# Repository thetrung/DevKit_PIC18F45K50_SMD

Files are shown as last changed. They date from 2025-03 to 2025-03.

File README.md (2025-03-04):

DevKit PIC18F45K50-SMD / Mini-USB
===================================
Basic USB Type-B DevKit I made to learn about **PIC18F45K50** microcontroller.

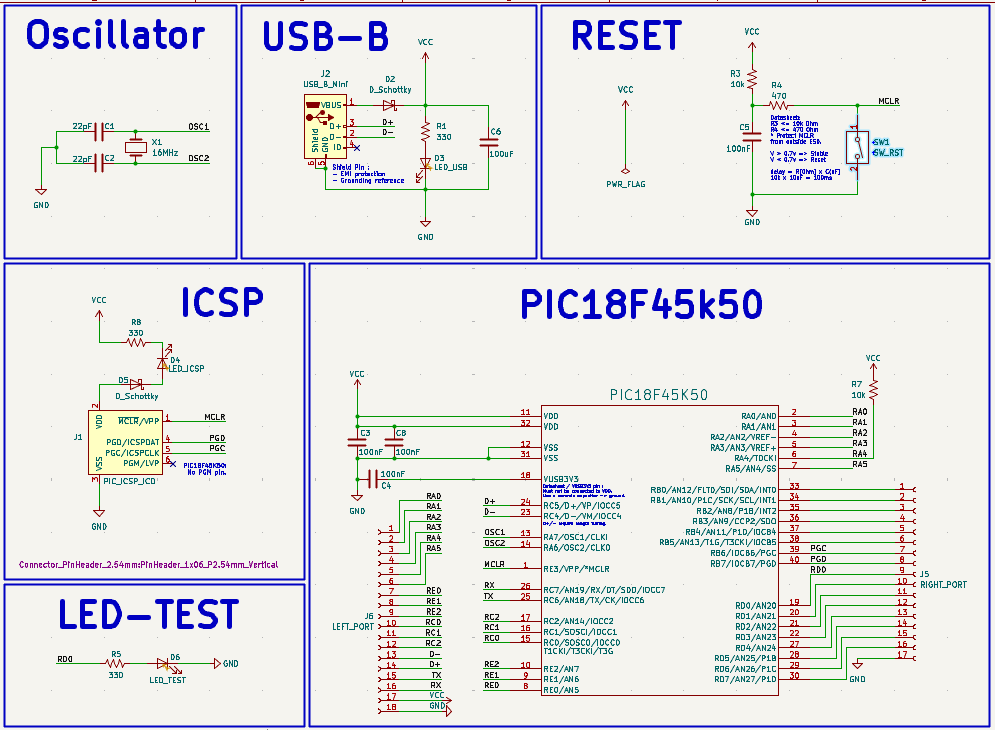
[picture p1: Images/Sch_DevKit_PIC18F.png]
overview


- **PIC18F45K50-I/MV** will be used specifically as UQFN-40(5x5) instead DIP-40 package in previous THT version.

I actually tried to put all SMD components on front side only. Used Mini-USB instead of USB-B in previous THT version. So this isn't optimized by any mean, just simply a practice to experience what SMD PCB Design look like & what challenge compare to THT ? Although initial goal was same size to a DIP-40. But Port hints are so valuable to remove.

### 1. Basic functionality :
- USB-powered 5V supply.
- USB-HID controllable with PIC18F45k50 with D+/D- pins.
- Reset Button -> Trigger MLCR-pin pull-down -> GND.
- Programming/Debugging with PICKIT-3 via ICSP pins.
- 5 pluggable PORTS : RA, RB, RC, RD, RE.
- LED at RD0 for Blink Test.

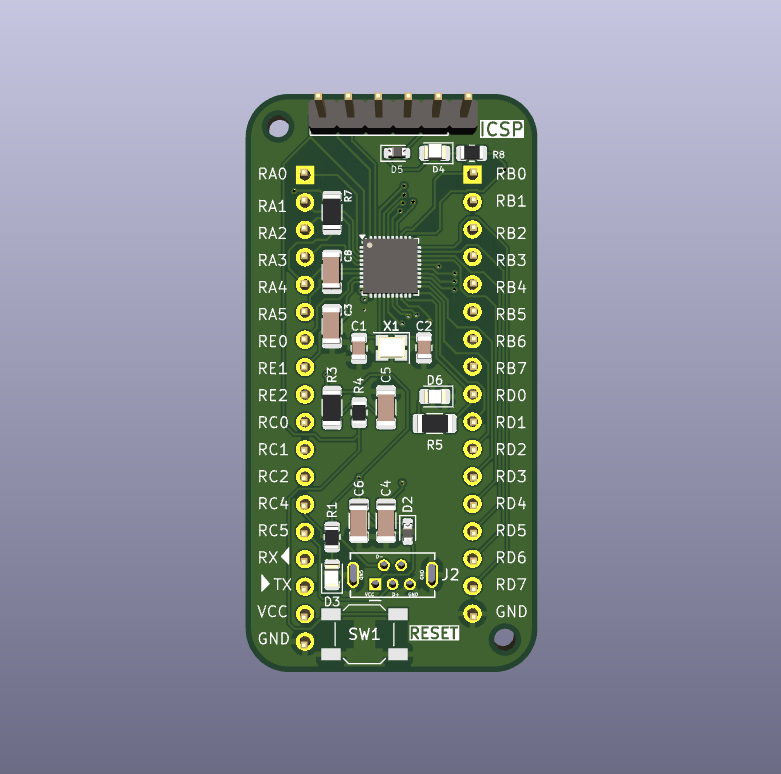
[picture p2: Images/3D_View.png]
3d_parts

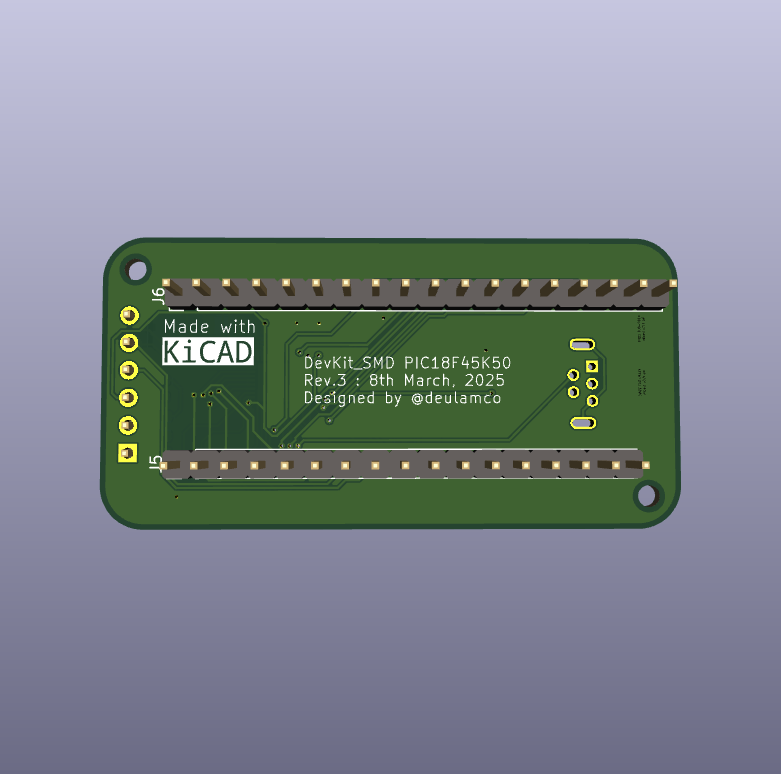
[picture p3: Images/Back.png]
back


### 2. TODO / Future extensions :
- Add Array : 
    - 4x4 12mm-Buttons pad.
    - 4x4 LEDs grid.
    - 16 Relays
      
- Add Gyro sensor.
- Add distance sensor.
- Add HLK-PM01 Module & Relay.
- Add built-in UART w/ CH340 !?
- Add LCD2004 support, with/without I2C module.
- Add WIFI/LoRA/Bluetooth by ESP32 support (?).

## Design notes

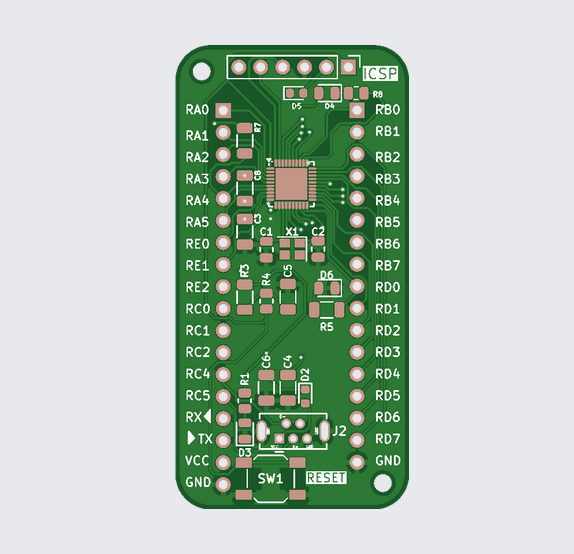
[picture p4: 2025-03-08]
Images/TOP_Placement.png

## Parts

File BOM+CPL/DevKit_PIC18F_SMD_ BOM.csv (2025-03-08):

Comment | Designator | Footprint | LCSC Part Number
22pF | C2,C1 | C_0805_2012Metric | C1804
100nF | C3,C5,C4,C8 | C_1206_3216Metric | C24497
100uF | C6 | C_1206_3216Metric | C15008
D_Schottky | D2,D5 | D_0603_1608Metric | C3758192
LED_TEST | D3,D4,D6 | LED_0805_2012Metric | C2297
PIC18F45K50-I/MV | PIC18F45K50 | QFN-40-1EP_5x5mm_P0.4mm_EP3.6x3.6mm | C638925
10k | R3,R7 | R_1206_3216Metric | C17902
470Ohm | R8,R4,R5,R1 | R_0805_2012Metric | C17710
16MHz | X1 | Crystal_SMD_2520-4Pin_2.5x2.0mm | C13738
SW_RST | SW1 | SW_SPST_SKQG_WithStem | C318884

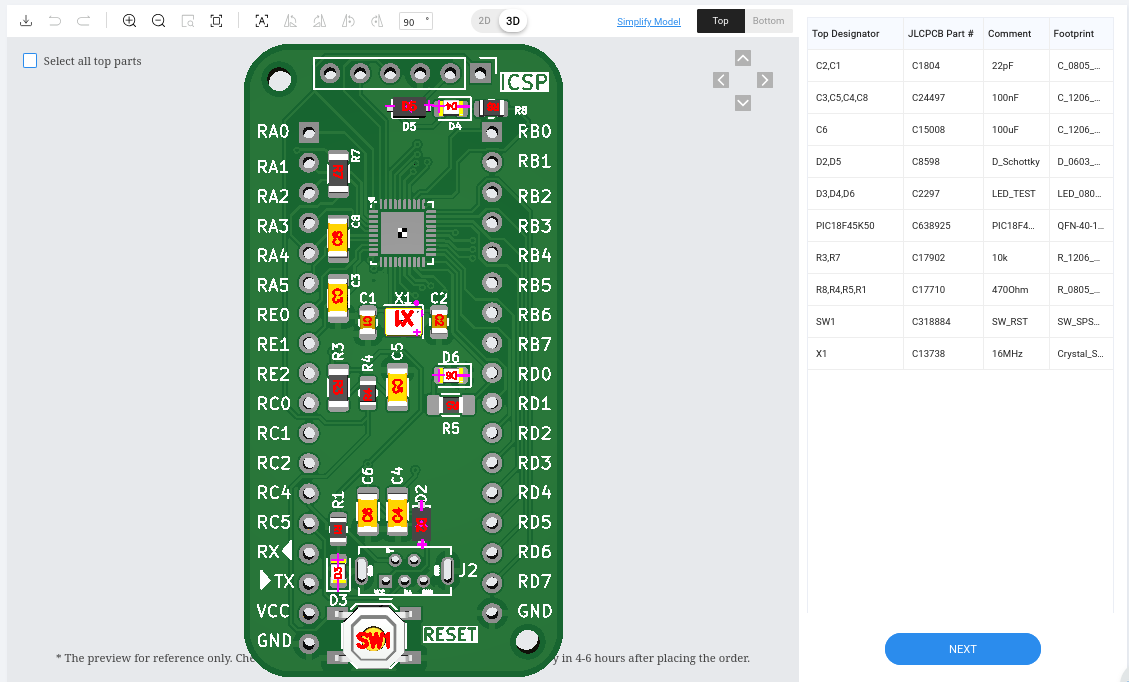
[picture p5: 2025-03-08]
Images/TOP_Parts.png

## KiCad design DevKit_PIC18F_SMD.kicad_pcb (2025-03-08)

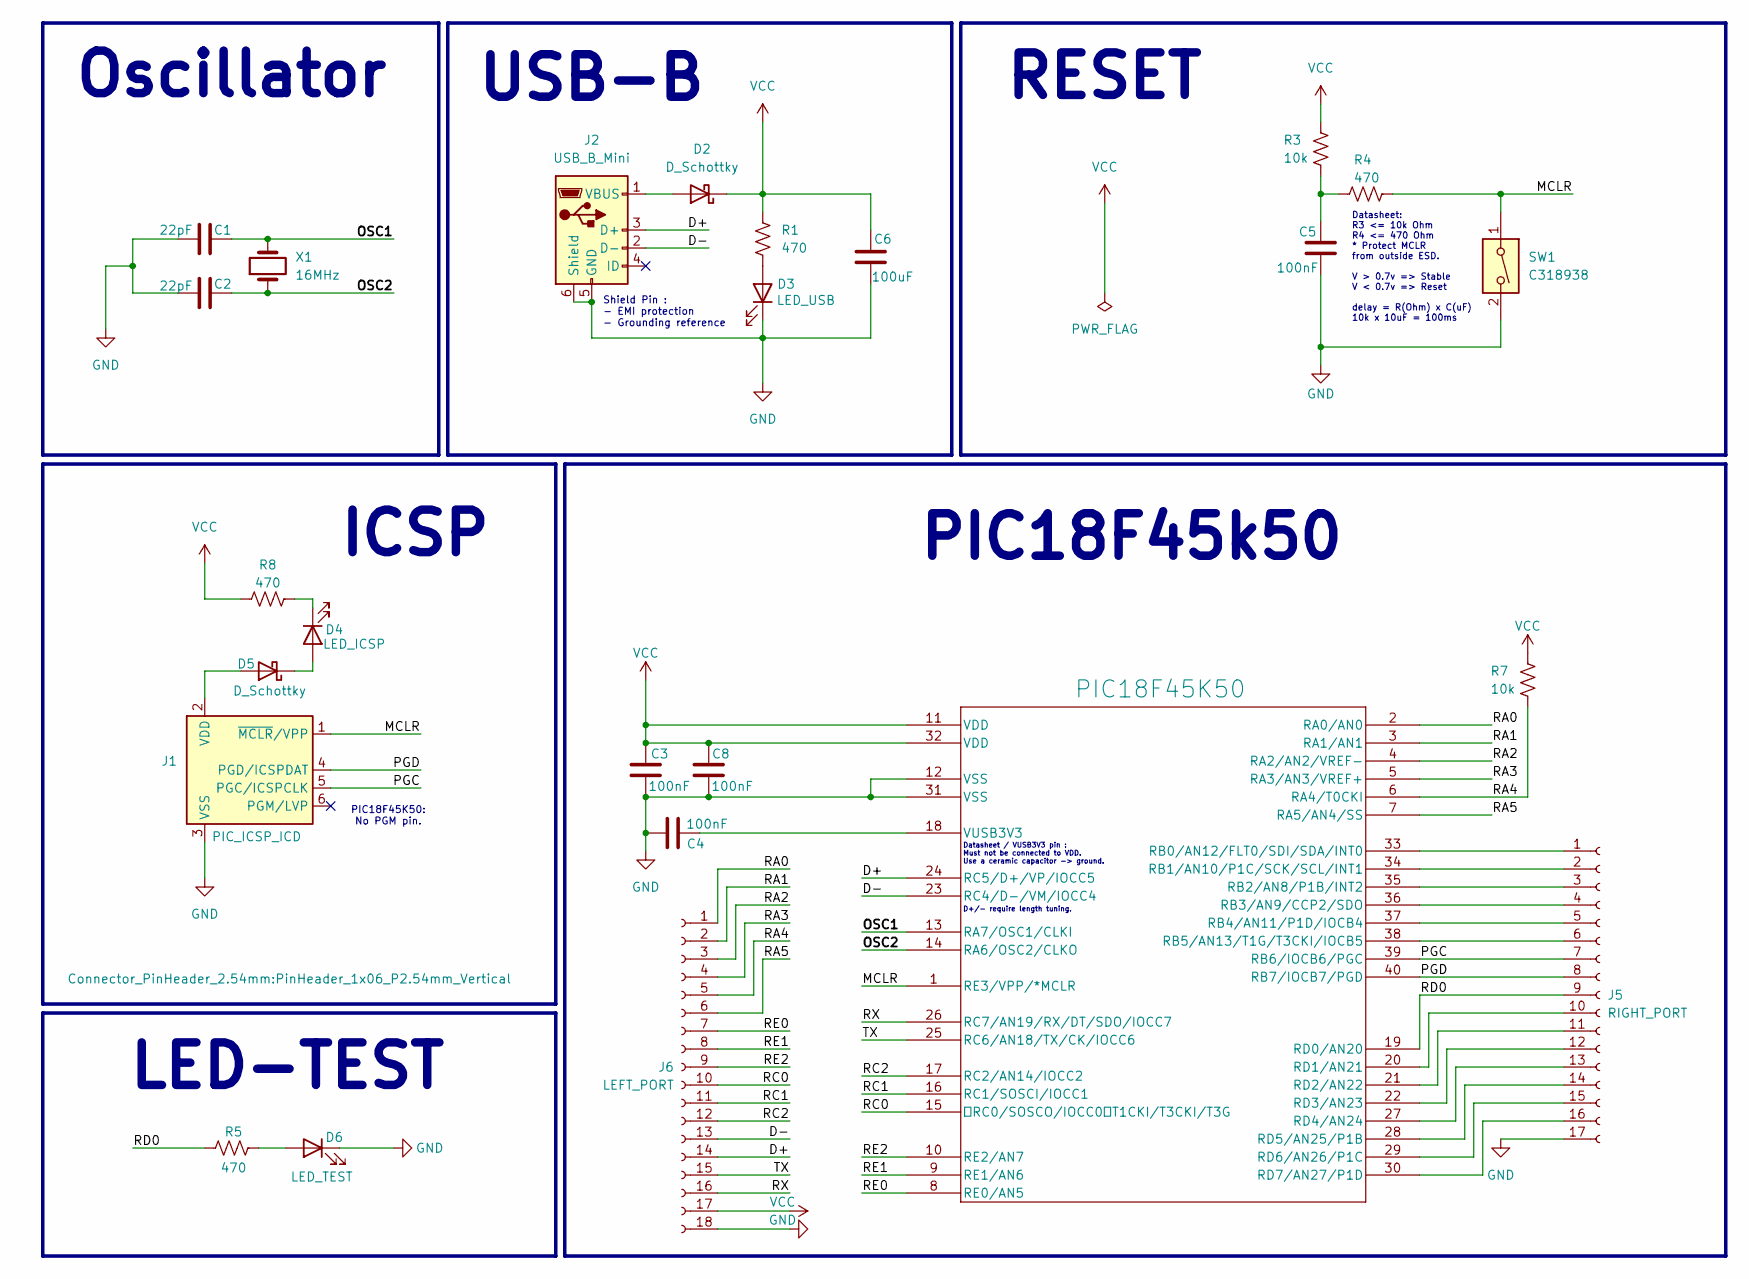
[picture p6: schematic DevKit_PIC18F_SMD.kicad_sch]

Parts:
C1, C2: 22pF; C_0805_2012Metric
C3, C4, C5, C8: 100nF; C_1206_3216Metric
C6: 100uF; C_1206_3216Metric
D2, D5: D_Schottky; D_0603_1608Metric
D3: LED_USB; LED_0805_2012Metric
D4: LED_ICSP; LED_0805_2012Metric
D6: LED_TEST; LED_0805_2012Metric
J1: PIC_ICSP_ICD; PinHeader_1x06_P2.54mm_Vertical
J2: USB_B_Mini; USB_Mini-B_Tensility_54-00023_Vertical
J5: RIGHT_PORT; PinHeader_1x17_P2.54mm_Vertical
J6: LEFT_PORT; PinHeader_1x18_P2.54mm_Vertical
PIC18F45K50: PIC18F45K50-I/MV; QFN-40-1EP_5x5mm_P0.4mm_EP3.6x3.6mm
R1, R4, R5, R8: 470; R_0805_2012Metric
R3, R7: 10k; R_1206_3216Metric
SW1: C318938; SW_SPST_SKQG_WithStem
X1: 16MHz; Crystal_SMD_2520-4Pin_2.5x2.0mm

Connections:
/D+: J2.3 (D+), J6.14, PIC18F45K50.24 (RC5/D+/VP/IOCC5)
/D-: J2.2 (D-), J6.13, PIC18F45K50.23 (RC4/D-/VM/IOCC4)
/MCLR: J1.1 (~MCLR/VPP), PIC18F45K50.1 (RE3/VPP/*MCLR), R4.1, SW1.1
/OSC1: C1.1, PIC18F45K50.13 (RA7/OSC1/CLKI), X1.2
/OSC2: C2.1, PIC18F45K50.14 (RA6/OSC2/CLKO), X1.1
/PGC: J1.5 (PGC/ICSPCLK), J5.7, PIC18F45K50.39 (RB6/IOCB6/PGC)
/PGD: J1.4 (PGD/ICSPDAT), J5.8, PIC18F45K50.40 (RB7/IOCB7/PGD)
/RA0: J6.1, PIC18F45K50.2 (RA0/AN0)
/RA1: J6.2, PIC18F45K50.3 (RA1/AN1)
/RA2: J6.3, PIC18F45K50.4 (RA2/AN2/VREF-)
/RA3: J6.4, PIC18F45K50.5 (RA3/AN3/VREF+)
/RA4: J6.5, PIC18F45K50.6 (RA4/T0CKI), R7.2
/RA5: J6.6, PIC18F45K50.7 (RA5/AN4/SS)
/RC0: J6.10, PIC18F45K50.15 (RC0/SOSCO/IOCC0 T1CKI/T3CKI/T3G)
/RC1: J6.11, PIC18F45K50.16 (RC1/SOSCI/IOCC1)
/RC2: J6.12, PIC18F45K50.17 (RC2/AN14/IOCC2)
/RD0: J5.9, PIC18F45K50.19 (RD0/AN20), R5.1
/RE0: J6.7, PIC18F45K50.8 (RE0/AN5)
/RE1: J6.8, PIC18F45K50.9 (RE1/AN6)
/RE2: J6.9, PIC18F45K50.10 (RE2/AN7)
/RX: J6.16, PIC18F45K50.26 (RC7/AN19/RX/DT/SDO/IOCC7)
/TX: J6.15, PIC18F45K50.25 (RC6/AN18/TX/CK/IOCC6)
GND: C1.2, C2.2, C3.2, C4.1, C5.1, C6.1, C8.2, D3.1 (K), D6.1 (K), J1.3 (VSS), J2.5 (GND), J2.6 (Shield), J5.17, J6.18, PIC18F45K50.12 (VSS), PIC18F45K50.31 (VSS), SW1.2
unnamed: C5.2, R3.2, R4.2
unnamed: D2.2 (A), J2.1 (VBUS)
unnamed: D3.2 (A), R1.2
unnamed: D4.2 (A), D5.1 (K)
unnamed: D4.1 (K), R8.2
unnamed: D5.2 (A), J1.2 (VDD)
unnamed: D6.2 (A), R5.2
unnamed: J5.1, PIC18F45K50.33 (RB0/AN12/FLT0/SDI/SDA/INT0)
unnamed: J5.2, PIC18F45K50.34 (RB1/AN10/P1C/SCK/SCL/INT1)
unnamed: J5.3, PIC18F45K50.35 (RB2/AN8/P1B/INT2)
unnamed: J5.4, PIC18F45K50.36 (RB3/AN9/CCP2/SDO)
unnamed: J5.5, PIC18F45K50.37 (RB4/AN11/P1D/IOCB4)
unnamed: J5.6, PIC18F45K50.38 (RB5/AN13/T1G/T3CKI/IOCB5)
unnamed: J5.10, PIC18F45K50.20 (RD1/AN21)
unnamed: J5.11, PIC18F45K50.21 (RD2/AN22)
unnamed: J5.12, PIC18F45K50.22 (RD3/AN23)
unnamed: J5.13, PIC18F45K50.27 (RD4/AN24)
unnamed: J5.14, PIC18F45K50.28 (RD5/AN25/P1B)
unnamed: J5.15, PIC18F45K50.29 (RD6/AN26/P1C)
unnamed: J5.16, PIC18F45K50.30 (RD7/AN27/P1D)
unnamed: C4.2, PIC18F45K50.18 (VUSB3V3)
VCC: C3.1, C6.2, C8.1, D2.1 (K), J6.17, PIC18F45K50.11 (VDD), PIC18F45K50.32 (VDD), R1.1, R3.1, R7.1, R8.1

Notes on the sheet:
RESET
USB-B
D+/- require length tuning.
ICSP
Shield Pin : - EMI protection - Grounding reference
Datasheet / VUSB3V3 pin : Must not be connected to VDD. Use a ceramic capacitor -> ground.
LED-TEST
Datasheet: R3 <= 10k Ohm R4 <= 470 Ohm * Protect MCLR from outside ESD. V > 0.7v => Stable V < 0.7v => Reset delay = R(Ohm) x C(uF) 10k x 10uF = 100ms
Oscillator
PIC18F45K50: No PGM pin.
PIC18F45k50

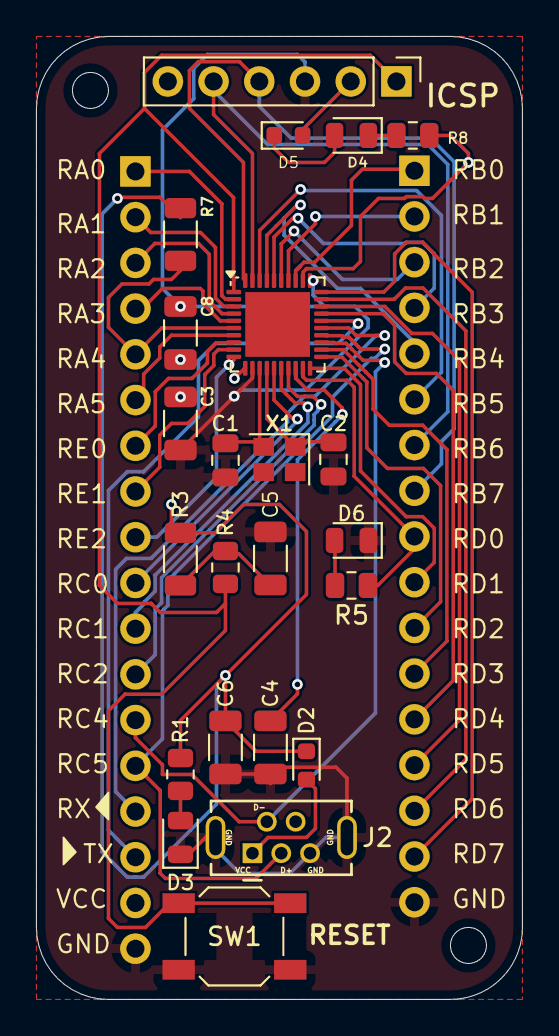
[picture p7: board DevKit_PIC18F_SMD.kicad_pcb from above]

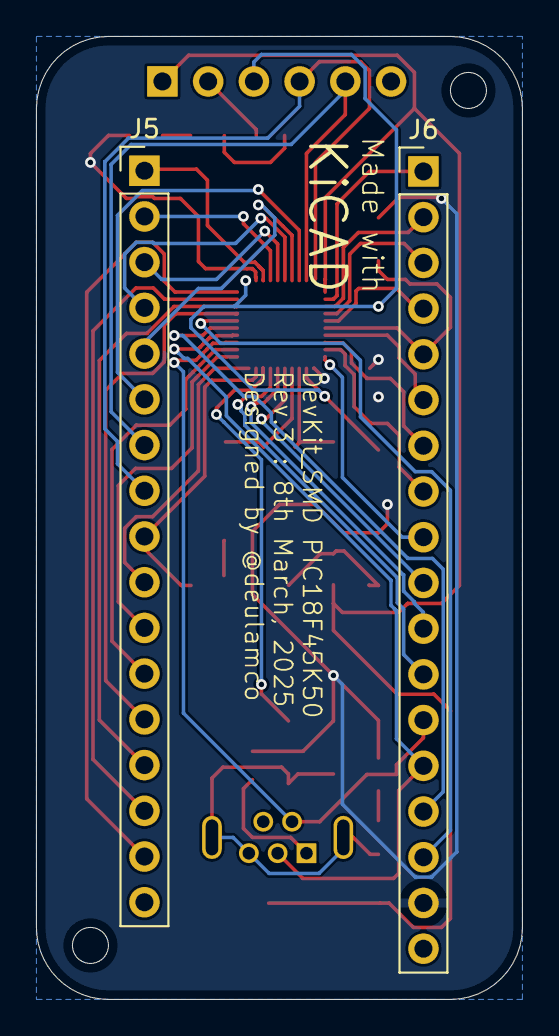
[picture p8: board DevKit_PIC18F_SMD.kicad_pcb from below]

Board: 2 copper layers, 27.0 x 53.5 mm, 25 parts (2 on the bottom side), 45 nets.

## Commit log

2025-03-04 made SMD version of prev DevKit rev.5
    [DevKit_PIC18F_SMD.kicad_pcb, DevKit_PIC18F_SMD.kicad_sch, PDIP40_P_MCH.stl]
2025-03-04 update images & comment.
    [DevKit_PIC18F_SMD.kicad_pcb, DevKit_PIC18F_SMD.kicad_sch]
2025-03-05 Added VCC/GND pins
    [DevKit_PIC18F_SMD.kicad_pcb, DevKit_PIC18F_SMD.kicad_sch]
2025-03-05 Remove PWR flag in Reset part, since we updated wrong pin setup in symbol PIC18F45K50.
    [DevKit_PIC18F_SMD.kicad_pcb, DevKit_PIC18F_SMD.kicad_sch, PDIP40_P_MCH.stl]
2025-03-07 rev.2 : and GND -> Left sockets & move RST_Button to bottom.
    [DevKit_PIC18F_SMD.kicad_pcb, DevKit_PIC18F_SMD.kicad_sch]
2025-03-07 Add mapped BOM+CPL
    [DevKit_PIC18F_SMD_ BOM.csv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]
2025-03-07 Optimize BOM cost to ~0/2pcs but minium 6 in total.
    [DevKit_PIC18F_SMD_ BOM.csv]
2025-03-08 Rev.3 : refine part-selection for JLCPCB fabrication & silkscreen.
    [DevKit_PIC18F_SMD.kicad_pcb, DevKit_PIC18F_SMD.kicad_sch, DevKit_PIC18F_SMD_ BOM.csv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]
2025-03-08 Fix R5 size 1206 -> 0805 & BOM of D5,D2 -> C3758192
    [DevKit_PIC18F_SMD.kicad_pcb, DevKit_PIC18F_SMD.kicad_sch, DevKit_PIC18F_SMD_ BOM.csv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]
